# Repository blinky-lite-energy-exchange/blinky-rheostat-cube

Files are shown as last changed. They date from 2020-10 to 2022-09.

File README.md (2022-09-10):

# Blinky Rheostat Cube
The Blinky Rheostat Cube is a stepper motor drive that is designed to drive 12V bi-polar stepper motors using the high current [DRV8825 Stepper Motor Driver Carrier](https://www.pololu.com/product/2133). The DRV8825 is driven by a [Teensy LC](https://www.pjrc.com/teensy/teensyLC.html) micro-controller. The Teensy LC micro-controller communicates to the [Blinky Rheostat tray](https://github.com/blinky-lite-energy-exchange/blinky-rheostat-tray) with a serial Bluetooth connection very similar to the connection method described in the [Blinky Bus Cube](https://github.com/Blinky-Lite-Exchange/blinky-bus-cube) project.

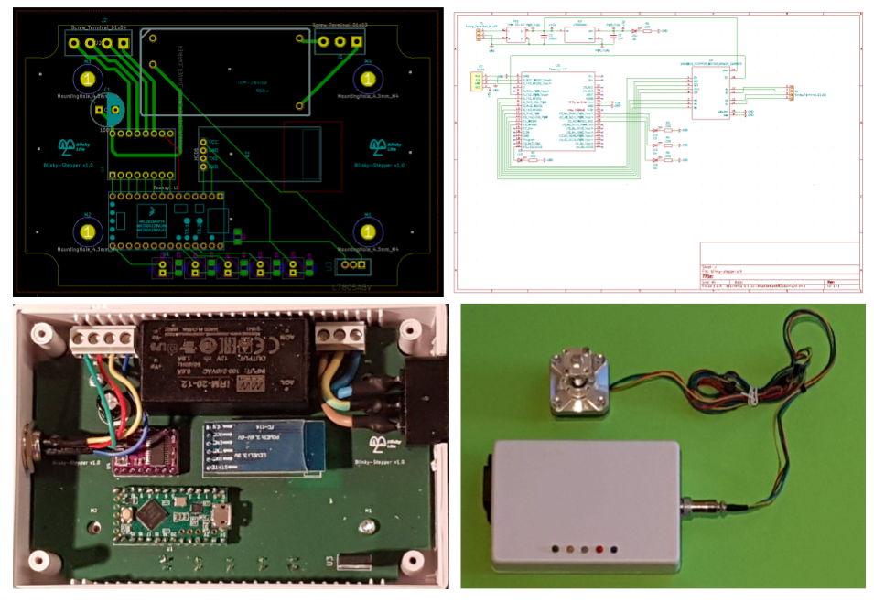
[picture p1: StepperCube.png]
<br>

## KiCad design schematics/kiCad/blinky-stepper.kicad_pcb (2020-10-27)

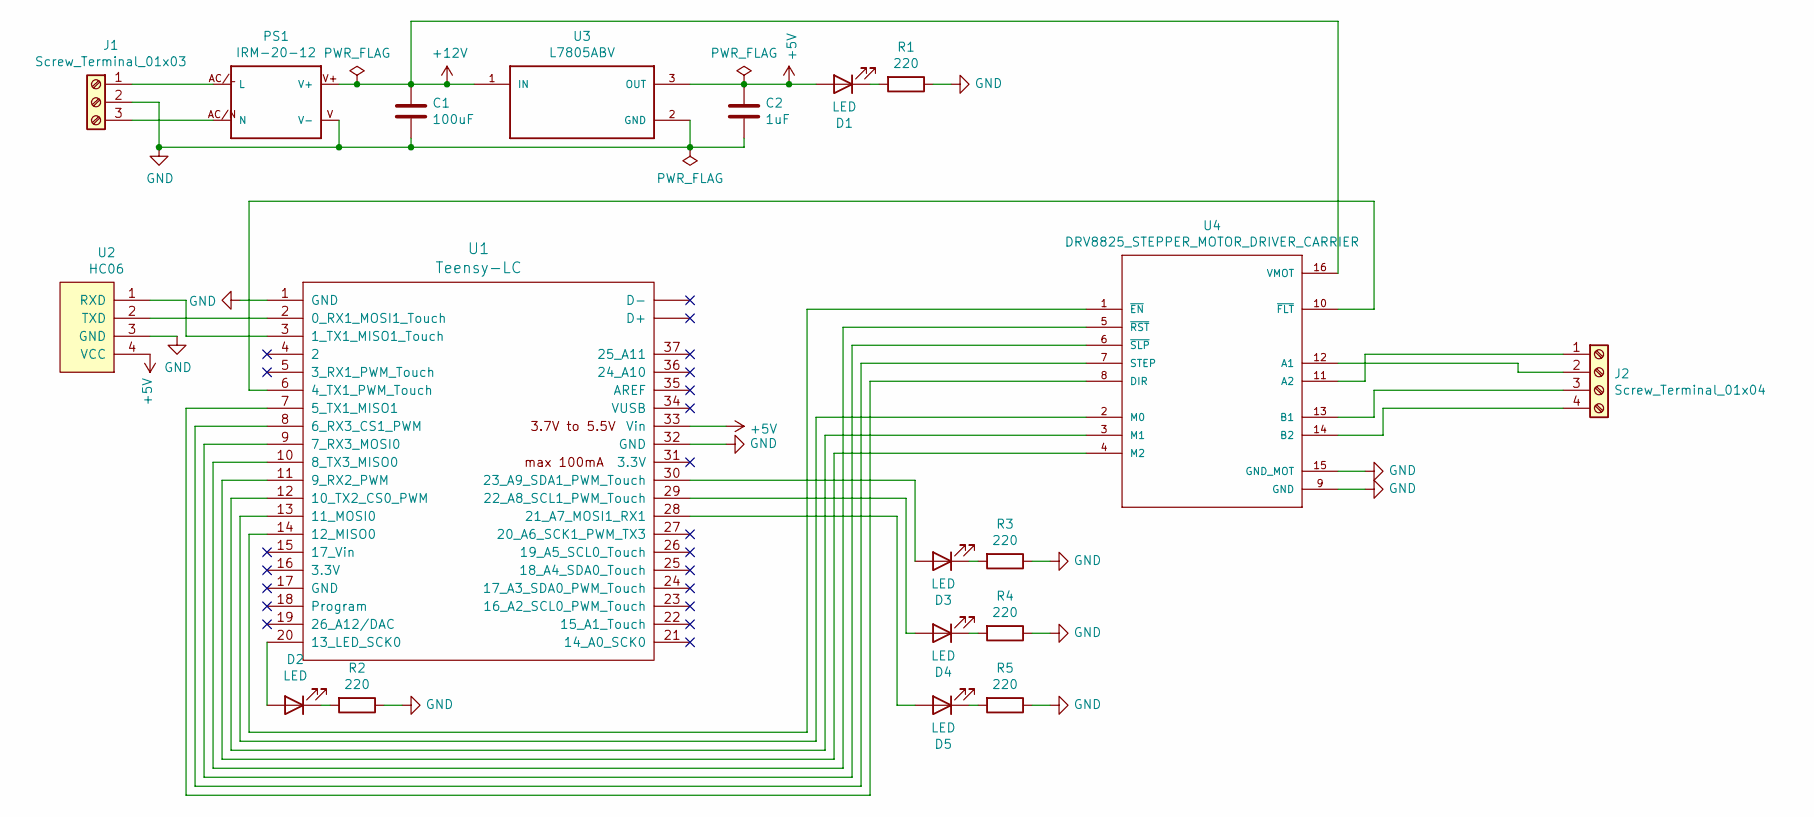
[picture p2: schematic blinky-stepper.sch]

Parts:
C1: 100uF; CP_Radial_D10.0mm_P5.00mm
C2: 1uF; C_1206_3216Metric_Pad1.42x1.75mm_HandSolder
D1, D2, D3, D4, D5: LED; LED_D5.0mm
J1: Screw_Terminal_01x03; TerminalBlock_bornier-3_P5.08mm
J2: Screw_Terminal_01x04; TerminalBlock_bornier-4_P5.08mm
PS1: IRM-20-12
R1, R2, R3, R4, R5: 220; R_1206_3216Metric_Pad1.42x1.75mm_HandSolder
U1: Teensy-LC; Teensy30_31_32_LC
U2: HC06
U3: L7805ABV; TO254P460X1020X1945-3P
U4: DRV8825_STEPPER_MOTOR_DRIVER_CARRIER; IC_DRV8825_STEPPER_MOTOR_DRIVER_CARRIER

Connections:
+5V: C2.1, D1.2 (A), U1.33 (Vin), U2.4 (VCC), U3.3 (OUT)
+12V: C1.1, PS1.V+, U3.1 (IN), U4.16 (VMOT)
GND: C1.2, C2.2, J1.2, PS1.V (V-), R1.1, R2.1, R3.1, R4.1, R5.1, U1.1 (GND), U1.32 (GND), U2.3 (GND), U3.2 (GND), U4.9 (GND), U4.15 (GND_MOT)
unnamed: D1.1 (K), R1.2
unnamed: D2.1 (K), R2.2
unnamed: D2.2 (A), U1.20 (13_LED_SCK0)
unnamed: D3.1 (K), R3.2
unnamed: D3.2 (A), U1.30 (23_A9_SDA1_PWM_Touch)
unnamed: D4.1 (K), R4.2
unnamed: D4.2 (A), U1.29 (22_A8_SCL1_PWM_Touch)
unnamed: D5.1 (K), R5.2
unnamed: D5.2 (A), U1.28 (21_A7_MOSI1_RX1)
unnamed: J1.1, PS1.AC/L (L)
unnamed: J1.3, PS1.AC/N (N)
unnamed: J2.1, U4.11 (A2)
unnamed: J2.2, U4.12 (A1)
unnamed: J2.3, U4.13 (B1)
unnamed: J2.4, U4.14 (B2)
unnamed: U1.2 (0_RX1_MOSI1_Touch), U2.2 (TXD)
unnamed: U1.3 (1_TX1_MISO1_Touch), U2.1 (RXD)
unnamed: U1.6 (4_TX1_PWM_Touch), U4.10 (~FLT~)
unnamed: U1.7 (5_TX1_MISO1), U4.8 (DIR)
unnamed: U1.8 (6_RX3_CS1_PWM), U4.7 (STEP)
unnamed: U1.9 (7_RX3_MOSI0), U4.6 (~SLP~)
unnamed: U1.10 (8_TX3_MISO0), U4.5 (~RST~)
unnamed: U1.11 (9_RX2_PWM), U4.4 (M2)
unnamed: U1.12 (10_TX2_CS0_PWM), U4.3 (M1)
unnamed: U1.13 (11_MOSI0), U4.2 (M0)
unnamed: U1.14 (12_MISO0), U4.1 (~EN~)

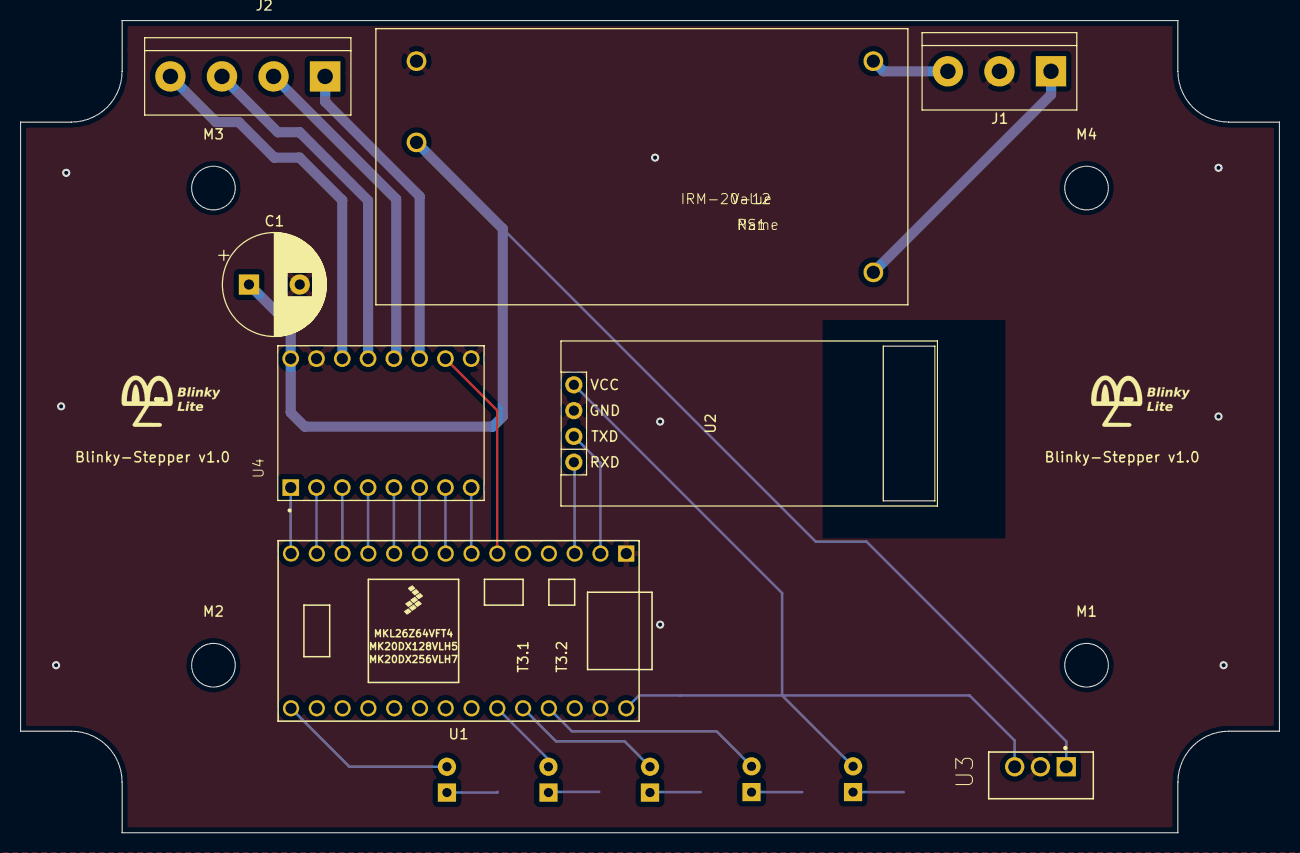
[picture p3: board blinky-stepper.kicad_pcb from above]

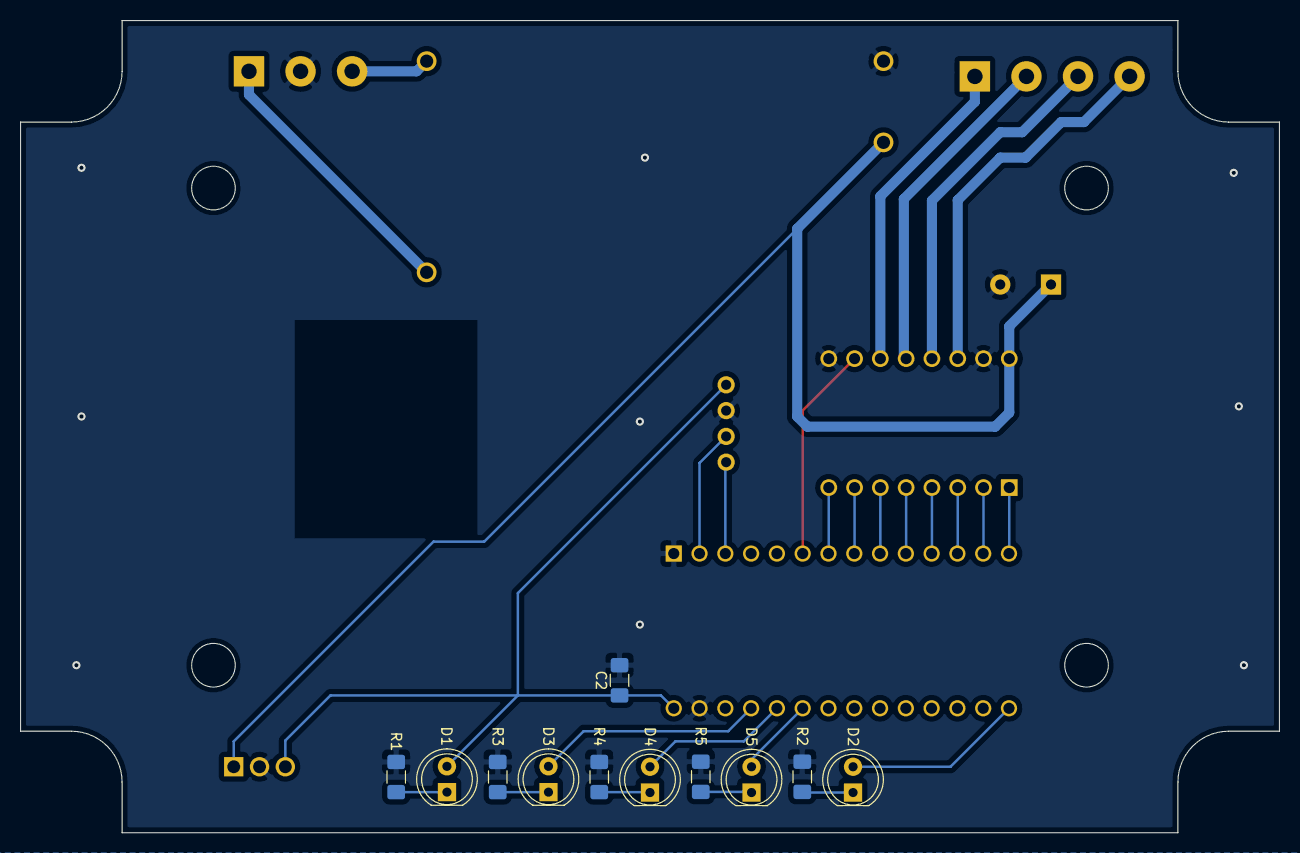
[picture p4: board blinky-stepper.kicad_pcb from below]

Board: 2 copper layers, 124.0 x 80.0 mm, 23 parts (11 on the bottom side), 29 nets.

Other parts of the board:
M1, M2, M3, M4: MountingHole_4.3mm_M4

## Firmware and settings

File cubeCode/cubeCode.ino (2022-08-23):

#include "BlinkyBus.h"
#define BAUD_RATE  19200
#define commLEDPin    13
#define BLINKYBUSBUFSIZE  10

#define notEnabledPin 12
#define m0Pin         11
#define m1Pin         10
#define m2Pin          9
#define notResetPin    8
#define notSleepPin    7
#define stepPin        6
#define dirPin         5
#define notFaultPin    4

#define redLEDPin     21
#define greenLEDPin   22
#define yellowLEDPin  23

union BlinkyBusUnion
{
  struct
  {
    int16_t state;
    int16_t moveMotor;
    int16_t resetStepReading;
    int16_t noStepsToTurn;
    int16_t stepForward;
    int16_t stepDelayuS;
    int16_t stayAwakeAfterRotation;
    int16_t resolution;
    int16_t delayAfterRotationmS;
    int16_t stepLocation;
  };
  int16_t buffer[BLINKYBUSBUFSIZE];
} bb;
BlinkyBus blinkyBus(bb.buffer, BLINKYBUSBUFSIZE, Serial1, commLEDPin);

int stepLocation = 0;

void setup()
{
  pinMode(notEnabledPin, OUTPUT);
  pinMode(m0Pin,         OUTPUT);
  pinMode(m1Pin,         OUTPUT);
  pinMode(m2Pin,         OUTPUT);
  pinMode(notResetPin,   OUTPUT);
  pinMode(notSleepPin,   OUTPUT);
  pinMode(stepPin,       OUTPUT);
  pinMode(dirPin,        OUTPUT);
  pinMode(notFaultPin,   INPUT);
  pinMode(commLEDPin,    OUTPUT);
  pinMode(redLEDPin,     OUTPUT);
  pinMode(greenLEDPin,   OUTPUT);
  pinMode(yellowLEDPin,  OUTPUT);
 
  digitalWrite(notEnabledPin, LOW);    
  digitalWrite(m0Pin,         LOW);    
  digitalWrite(m1Pin,         LOW);    
  digitalWrite(m2Pin,         LOW);    
  digitalWrite(notResetPin,  HIGH);    
  digitalWrite(notSleepPin,   LOW);    
  digitalWrite(commLEDPin,    LOW);    
  digitalWrite(redLEDPin,     LOW);    
  digitalWrite(greenLEDPin,   LOW);    
  digitalWrite(yellowLEDPin,  LOW);    

  bb.state               = 1;
  bb.moveMotor              = 0;
  bb.resetStepReading       = 0;
  bb.noStepsToTurn          = 0;
  bb.stepForward            = 1;
  bb.stepDelayuS            = 10000;
  bb.stayAwakeAfterRotation = 0;
  bb.resolution             = 0;
  bb.delayAfterRotationmS   = 100;
  bb.stepLocation           = 0;
  
  wakeup(0);
  setResolution(bb.resolution);

  Serial1.begin(BAUD_RATE);
  blinkyBus.start();
  delay(1000);
}

void loop()
{
  if (blinkyBus.poll() == 2)
  {
    if (blinkyBus.getLastWriteAddress() == 9)
    {
      stepLocation = (int) blinkyBus.getLastWriteValue();
    }
  }

  setResolution(bb.resolution);
  if (bb.resetStepReading > 0)
  {
    stepLocation = 0;
    bb.stepLocation = 0;
    bb.resetStepReading = 0;
  }
  wakeup(bb.stayAwakeAfterRotation);

  if (bb.moveMotor > 0)
  {
    wakeup(1);
    rotate(bb.noStepsToTurn, bb.stepDelayuS, bb.stepForward);
    delay(bb.delayAfterRotationmS);
    wakeup(bb.stayAwakeAfterRotation);
    bb.moveMotor = 0;
  }

  delay(50);
}
void incrementStepCounter()
{
    if (bb.stepForward > 0 )
    {
      stepLocation = stepLocation + 1;
    }
    else
    {
      stepLocation = stepLocation - 1;
    }
    bb.stepLocation = (int16_t) stepLocation;
}
void wakeup(int16_t wake)
{
  digitalWrite(redLEDPin,   wake);    
  digitalWrite(notSleepPin, wake);  
  delay(10);  
}
void rotate(int16_t steps, int16_t stepDelayuS, int16_t stepForward)
{
  digitalWrite(greenLEDPin,   HIGH);    
  digitalWrite(yellowLEDPin,   stepForward);    
  digitalWrite(dirPin, stepForward);
  for (int16_t i = 0; i < steps; i++) 
  {
    if (bb.moveMotor > 0)
    {
      // These four lines result in 1 step:
      digitalWrite(stepPin, HIGH);
      delayMicroseconds((int)stepDelayuS);
      digitalWrite(stepPin, LOW);
      delayMicroseconds((int) stepDelayuS);
      incrementStepCounter();
      blinkyBus.poll();
    }
    else
    {
      i = steps;
      delay(bb.delayAfterRotationmS);
      wakeup(bb.stayAwakeAfterRotation);
    }
  }
  digitalWrite(greenLEDPin,   LOW);    
  digitalWrite(yellowLEDPin,   LOW);    
}
int16_t setResolution(int16_t ires)
{
  int16_t iresSet = ires;
  int16_t iresSetDec = 1;
  if (ires < 0) iresSet = 0;
  if (ires > 5) iresSet = 5;
  switch (iresSet) 
  {
    case 0:
        digitalWrite(m0Pin,         LOW);    
        digitalWrite(m1Pin,         LOW);    
        digitalWrite(m2Pin,         LOW);    
      break;
    case 1:
        digitalWrite(m0Pin,        HIGH);    
        digitalWrite(m1Pin,         LOW);    
        digitalWrite(m2Pin,         LOW);    
      break;
    case 2:
        digitalWrite(m0Pin,         LOW);    
        digitalWrite(m1Pin,        HIGH);    
        digitalWrite(m2Pin,         LOW);    
      break;
    case 3:
        digitalWrite(m0Pin,        HIGH);    
        digitalWrite(m1Pin,        HIGH);    
        digitalWrite(m2Pin,         LOW);    
      break;
    case 4:
        digitalWrite(m0Pin,         LOW);    
        digitalWrite(m1Pin,         LOW);    
        digitalWrite(m2Pin,        HIGH);    
      break;
    case 5:
        digitalWrite(m0Pin,        HIGH);    
        digitalWrite(m1Pin,         LOW);    
        digitalWrite(m2Pin,        HIGH);    
      break;
    default:
        digitalWrite(m0Pin,         LOW);    
        digitalWrite(m1Pin,         LOW);    
        digitalWrite(m2Pin,         LOW);    
        iresSet = 0;
      break;
  }
  for (int i = 0; i < iresSet; i++) 
  {
    iresSetDec = iresSetDec * 2;
  }  
  return iresSetDec;
}

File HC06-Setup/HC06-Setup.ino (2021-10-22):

String at = "AT";
String deviceName = "AT+NAMESM01";
String password = "AT+PIN5822";
String baudRate = "AT+BAUD5";
// Command Reference
// http://www.martyncurrey.com/hc-06-hc01-comv2-0/
/*
1——— 1200
2——— 2400
3——— 4800
4——— 9600
5——— 19200
6——— 38400
7——— 57600
8——— 115200
 */
char commandChar[32];


void setup()
{
  Serial.begin(9600);
  Serial1.begin(19200);
  sendATCommand(at); 
  sendATCommand(deviceName);
//  sendATCommand(password);
//  sendATCommand(baudRate);
}

void loop()
{
}
void sendATCommand(String ATcommand)
{
  int commandLength = ATcommand.length();
  for (int ii = 0; ii < commandLength; ++ii)
  {
    Serial1.write(ATcommand.charAt(ii)); delay(50);
  }
  delay(500);
  Serial.print("AT response: ");
  while (Serial1.available())
  { 
    Serial.write(Serial1.read());
  }
  Serial.println();
}

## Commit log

2020-10-26 working prototype code
    [blinky-lite-basicBom.csv, blinky-stepper.kicad_pcb, blinky-stepper.sch]
2020-10-27 pcb finished
    [blinky-stepper.kicad_pcb, blinky-stepper.sch]
